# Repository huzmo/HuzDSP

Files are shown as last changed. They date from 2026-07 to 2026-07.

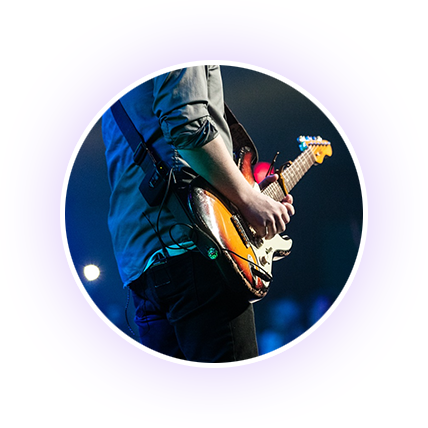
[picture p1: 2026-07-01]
Firmware/Drivers/lvgl-release-v9.5/demos/music/assets/png/480_png/cover_1.png

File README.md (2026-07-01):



<div align="center">
  <a href="https://github.com/github_username/repo_name">
    
  </a>

  <h3 align="center">HUZDSP</h3>

  <p align="center">
    Digital multi-effects guitar pedal featuring 2 input channels, 48kHz sampling, and 24-bit audio and open-source software with over 720 unique effect combinations per channel.
    <br />
    <br />
    &middot;
    <a href="https://youtube.com/shorts/TF-euVBcPBo?si=U8Q8GrKw2UyFqoOQ">View Demo</a>
    &middot;
  </p>
</div>

<!-- MARKDOWN LINKS & IMAGES -->
[product-screenshot]: images/screenshot.png

---

## Table of Contents

- [Overview](#overview)
- [Hardware](#hardware)
  - [Audio Signal Chain](#audio-signal-chain)
  - [Inputs / Outputs](#inputs--outputs)
  - [Power](#power)
  - [PCB / Physical Design](#pcb--physical-design)
- [Firmware](#firmware)
  - [Audio Processing Pipeline](#audio-processing-pipeline)
  - [Effect Framework](#effect-framework)
  - [Memory Map](#memory-map)
  - [Drivers / Peripherals](#drivers--peripherals)
- [Performance](#performance)
  - [CPU Utilization](#cpu-utilization)
  - [Memory Usage](#memory-usage)
  - [Audio Quality](#audio-quality)
- [Challenges](#challenges)
  - [Real-Time DSP Constraints](#real-time-dsp-constraints)
  - [Noise / Signal Integrity](#noise--signal-integrity)
  - [Resource Limitations](#resource-limitations)
  - [Modular Effect Integration](#modular-effect-integration)
- [Future Improvements](#future-improvements)
- [Media](#media)

---

## Overview

HuzDSP is a digital multi-effects guitar pedal, which pairs an STM32H743 microcontroller, a CS4270 audio codec, and an ILI9488 TFT display, running on FreeRTOS with an LVGL-based UI for real-time parameter control and effect chaining.

The goal of this project was to build a complete, professional-grade embedded audio platform rather than a single fixed-function pedal, with a 24-bit/48kHz signal path and a modular effects architecture that supports chaining multiple effects together, configuring them through UI, and extending the effect library without touching the core audio engine. Effects implemented so far include [effects list.

<p align="right">(<a href="#readme-top">back to top</a>)</p>

---

## Hardware

### Audio Signal Chain

Fundamentally, the signal flows through a linear path: beginning as an analog input from an external source, the signal passes through a buffer stage and is filtered with a cutoff at 27.6KHz to eliminate frequencies above the audible band. The filtered signal is then digitized by the ADC stage of the codec, after which the MCU reads and processes the data in real time before it is finally output and filtered back to analog on the way out.



### Inputs / Outputs

- 2x mono instrument inputs
- 2x mono instrument outputs
- 1x navigation encoder
- 3x parameter encoders
- 1x master volume potentiometer
- 480x320 LCD
- USB-C connector, reserved for future audio input/output to enable full audio interface functionality
- DC barrel jack for 9V-12V supply

### Power

The board is powered through a DC barrel jack and accepts 9V–12V, center-negative. Full supply voltage is used for the analog input/output op-amp stages. A reference voltage at half-supply is generated by a buffered resistor divider for biasing the op-amp stages. This rail is then stepped down to +5V for the codec and +3.3V for the remaining circuitry using DC-DC switching regulators, placed on the opposite end of the board from sensitive analog componentry to minimize switching noise coupling.

### PCB / Physical Design

A 4-layer board was chosen for this design, as it allows for larger ground planes with shorter return paths. A dedicated power layer simplifies routing and improves overall performance.

Physically, the board is designed to act as a shield for the LCD display; the mechanical design is simplified by having the board slot into the display and have the mounting holes lined up. This reduces the amount of wires present in the design and minimizes the length of the path the SPI and GPIO signals have to travel to reach the display processor.

To aid signal integrity, analog, power, and digital circuitry are separated from one another, and high-speed digital traces are routed away from analog sections. A solid ground plane sits directly below the first signal layer to reduce coupling between layers.

<p align="right">(<a href="#readme-top">back to top</a>)</p>

---

## Firmware

### Audio Processing Pipeline



### Effect Framework

One of the core design features of this project was to incorporate a framework for modular effects; effectively being able to add as many different kinds of effects as long as a simple template is followed. By decoupling parameter and state data from the effect's process function, an arbitrary process function can be passed into the effect loop without needing to manage unique local variables, previous states, or per-effect initialization logic elsewhere in the codebase.

Each effect is split into two parts: a structure that stores an assignable process function pointer, an array of parameters, and a block of state. The process function can be assigned freely at runtime and represents the per-sample algorithm used to achieve the desired effect. A pointer to the effect structure is passed into the process function, which reads the appropriate parameters and writes to the state block to hold constants, previous sample values, or any other data needed on the next sample cycle.

This framework not only allows for an intuitive, modular approach to adding new effects, but also saves memory by allocating each effect slot at compile-time and assigning the process function pointer at runtime, rather than dynamically creating and destroying effect instances during operation. This also guarantees exactly one instance of each effect exists in memory; if multiple effect slots use the same effect type, their function pointers all reference that single shared instance, regardless of how many slots use it.

### Memory Map

Memory is partitioned into two logical regions. Uncached allocations begin at `0x30000000` and are reserved for the audio path, while cacheable memory starting at `0x24000000` is used for display buffers. For the large display buffers, cacheability is a major advantage, as it allows for low-latency renders for frames which have not been flagged for change by LVGL. As audio data is a constant stream of changing values, caching would result in corrupt data, and continuously caching and uncaching would increase latency rather than reduce it. Therefore, audio buffers are allocated in a region which is strictly uncacheable. Each area can be read freely, which keeps managing state between the audio and display stacks simple.

### Drivers / Peripherals

- **LCD**: ILI9488 driver, adapted and optimized from an existing open-source base for this project's needs
- **Codec**: Custom CS4270 driver, written from scratch (I2C register configuration, reset sequencing)
- **SAI**: Used to read and write audio data to/from the codec
- **I2C**: Used to configure codec registers
- **SPI**: Used to drive the ILI9488 LCD display
- **Master volume potentiometer**: Interfaced by polling and filling a DMA buffer with data inside a dedicated task
- **Encoders**: Interfaced using hardware timers in encoder mode; push buttons are handled via interrupts

<p align="right">(<a href="#readme-top">back to top</a>)</p>

---

## Performance

### CPU Utilization



### Memory Usage



### Audio Quality



0.12ms measured latency with slight distortion caused by the aforementioned sources.

<p align="right">(<a href="#readme-top">back to top</a>)</p>

---

## Challenges

### Real-Time DSP Constraints

Running multiple DSP effects in a chain on a single sample-by-sample loop means every effect has a fixed time budget before the next audio sample is due. Effects like the flanger and chorus, which rely on buffered history and interpolation, had to be profiled and optimized carefully to stay within that budget without introducing audible glitches or dropouts.

### Noise / Signal Integrity

Keeping the analog signal path clean while running high-speed digital logic and switching power regulators on the same board meant analog, digital, and power circuitry had to be kept separate from one another, with high-speed digital routed away from analog sections. Coil whine from the TPS563200 buck converter was identified as one source of analog noise on the current board revision, and has been noted as a target for layout improvements in a future hardware revision.

### Resource Limitations

Balancing the audio buffers, display framebuffers, and RTOS task stacks within the STM32H743's memory map required explicit partitioning between cacheable and non-cacheable regions, along with careful DMA buffer placement, to avoid cache-coherency issues between the CPU and the DMA-driven audio and display peripherals.

### Modular Effect Integration

Designing the effect framework so new effects could be added without modifying the core audio engine took a few iterations to get right. The function-pointer-based dispatch approach, paired with per-effect parameter and state arrays, ended up being the design that struck the right balance between flexibility and the deterministic, low-overhead execution real-time audio processing demands.

<p align="right">(<a href="#readme-top">back to top</a>)</p>

---

## Future Improvements

- Address coil whine from the TPS563200 buck converter in a rev2 PCB layout
- Bring up USB-C audio interface functionality for full audio interface mode
- Expand the effect library beyond the current selection
- Continued UI refinement
- Implement EQ
  
<p align="right">(<a href="#readme-top">back to top</a>)</p>

---

## Media



Test Rig

<p align="right">(<a href="#readme-top">back to top</a>)</p>

---

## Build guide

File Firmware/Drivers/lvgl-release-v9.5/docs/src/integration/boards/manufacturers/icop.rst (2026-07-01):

====
ICOP
====

ICOP makes industrial computer hardware and the development tools for them.
ICOP offers an uncommon combination of hardware and software which distinguishes
them from other board vendors.

For a start, their products are not evaluation boards. They are ready-to-use
industrial PCs. They are a complete solution electrically and mechanically.

They are programmed with the Arduino IDE. You write your embedded application
logic and UI using the Arduino framework and its library ecosystem. Arduino is a
great abstraction to solve real problems when it's available for a platform.
ICOP is one such platform. You have access to all the popular open source
Arduino libraries. There is also support for installing Windows 11 on it.

Inside most of ICOP's panel PCs is an x86 processor. They are DM&P Vortex86
series chips. They execute 32-bit i586 machine code. This has interesting
implications, especially since the programming environment is as low-level as Arduino.
It's a rare case of an x86 CPU being used in a real-time setting.

Panel PCs
*********

These are PCs which are designed to be mounted in a panel. They are more
powerful than typical HMIs.

QEC-PPC-M-090T
--------------

This is an x86 panel PC which you can program using the Arduino IDE.
It has two cores. One core is dedicated to EtherCAT so the other is free
for application logic.

See the
`LVGL port repo <https://github.com/lvgl/lv_port_icop_qec_ppc_m_090t>`_
to get started creating a project for it with LVGL.

See the
`store page <https://www.icop.com.tw/product/QEC-PPC-M-090T>`_
for documentation and the ordering information.

Specs
~~~~~

CPU and Memory

- CPU: 533 MHz Vortex86EX2 32-bit x86 CPU
- RAM: 512MB/1GB DDR3
- Flash: 2GB SLC eMMC, 32MB SPI Flash

Display and Touch

- Resolution: 1024x600
- Display Size: 9"
- Interface: VGA
- Color Depth: 16-bit
- Technology: TFT
- DPI: 132 px/inch
- Touch Pad: Resistive

Connectivity

- Ethernet
- USB x3
- Headphone

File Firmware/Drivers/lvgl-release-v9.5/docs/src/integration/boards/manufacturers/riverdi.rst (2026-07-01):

=======
Riverdi
=======

`Riverdi <https://riverdi.com/>`__ specializes in making high quality
displays and the boards that carry them. They offer solutions that
range from simple display panels to intelligent displays, and
everything in between.

- STM32 Embedded Displays
- Single Board Computer Displays
- EVE Intelligent Displays
- HDMI Displays
- Evaluation Boards
- RGB, LVDS, MIPI DSI LCD Displays

STM32 Embedded Displays
***********************

The STM32 Embedded Displays have an STM32 MCU onboard which makes
it possible to embed an entire application into the device. LVGL
is well-suited to these boards.

lv_port_riverdi_stm32u5
-----------------------

`lv_port_riverdi_stm32u5 <https://github.com/lvgl/lv_port_riverdi_stm32u5>`_
is a port repo of LVGL which supports all 5-inch Riverdi STM32
Embedded Displays.

- `RVT50HQSNWC00-B <https://riverdi.com/product/5-inch-lcd-display-capacitive-touch-panel-optical-bonding-uxtouch-stm32u5-rvt50hqsnwc00-b>`_
- `RVT50HQSNWC00 <https://riverdi.com/product/5-inch-lcd-display-capacitive-touch-panel-air-bonding-uxtouch-stm32u5-rvt50hqsnwc00>`_
- `RVT50HQSFWCA0 <https://riverdi.com/product/5-inch-lcd-display-capacitive-touch-panel-air-bonding-atouch-frame-stm32u5-rvt50hqsfwca0>`_
- `RVT50HQSNWCA0 <https://riverdi.com/product/5-inch-lcd-display-capacitive-touch-panel-air-bonding-atouch-stm32u5-rvt50hqsnwca0>`_
- `RVT50HQSFWN00 <https://riverdi.com/product/5-inch-lcd-display-stm32u5-frame-rvt50hqsfwn00>`_
- `RVT50HQSNWN00 <https://riverdi.com/product/5-inch-lcd-display-stm32u5-rvt50hqsnwn00>`_

It natively supports the embedded NeoChrom GPU thanks to LVGL's support
for :ref:`NeoChrom <neochrom>`. NemaVG --- an extension to NeoChrom's
base support --- is implemented by this MCU.

The MCU has an LCD driver peripheral which LVGL uses to update the
display. See the :ref:`LTDC <stm32_ltdc_driver>` driver docs
for more info and how to customize its use.

Single-Board Computer Displays
******************************

The Single-Board Computer Displays are ready to use with
:ref:`Toradex <toradex>` Dahlia and Mallow carrier boards. In fact,
those carrier boards are compatible with all 34-pin Riverdi
MIPI-DSI displays.

Other Products
**************

The **EVE Intelligent Displays** feature a Bridgetek EVE graphics
controller IC so that the display can be controlled using
high-level drawing commands over a lower-bandwidth interface than
RGB, MIPI, etc.

The **HDMI Displays** sport an HDMI interface for streamlined
integration with PCs or SBCs. These displays are still low-profile
so they can be embedded into custom fixtures with ease.

The **Evaluation Boards** are affordable carrier boards for getting
Riverdi display panels up and running before designing or buying a
carrier board for a production application.

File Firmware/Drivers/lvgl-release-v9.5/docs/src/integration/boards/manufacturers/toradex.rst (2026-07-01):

.. include:: /include/substitutions.txt
.. _toradex:

=======
Toradex
=======

About Toradex
*************

Toradex specializes in manufacturing high-quality embedded computing solutions
based on System on Module units (SoMs). These boards and modules are designed to
meet the needs of industrial and commercial applications, offering reliability,
longevity, and scalability. Leveraging industry-standard frameworks like Yocto
Project, Toradex enables customers to create tailored embedded systems with
ease, ensuring compatibility and flexibility.

Products Portfolio
******************

Toradex offers a wide range of system-on-modules (SoMs) and carrier boards
designed for various applications and industries. Here's a basic overview to
help you navigate the portfolio.

Aquila
------

Aquila is a new System on Module standard expanding the Toradex portfolio to
new heights, offering unparalleled performance for computationally intensive
CPU, machine learning, and vision workloads.

To power next-gen's AI requirements in industrial and other harsh environments,
Aquila introduces a proven connector: the 400-pin board-to-board connector,
making the board extra reliable, especially in these environments.

Aquila Computer on Module:

    - `Aquila iMX95 <https://www.toradex.com/computer-on-modules/
      aquila-arm-family/nxp-imx95>`_
    - `Aquila AM69 <https://www.toradex.com/computer-on-modules/
      aquila-arm-family/ti-am69>`_

Aquila Carrier Boards:

    - `Clover <https://www.toradex.com/products/carrier-board/clover>`_
    - `Aquila Development Board <https://www.toradex.com/products/carrier-board/
      aquila-development-board-kit>`_

Apalis
------

Apalis is a scalable System on Module (SoM) / Computer on Module (CoM) family
that aims to provide high performance in a compact form factor. Apalis enables
the development of advanced and robust products within a short time and with
low risks. Apalis modules scale to the highest performance in the Toradex
product range, and they provide the most interfaces of any product line on the
314-pin MXM connectors. Apalis modules are suited to a larger number of
applications in such fields as healthcare, industrial automation, robotics,
smart cities and many more. Apalis modules are supported by Toradex software
offerings and the company's rich ecosystem of other products and services.

Apalis Computer on Module:

    - `Apalis iMX8 <https://www.toradex.com/computer-on-modules/
      apalis-arm-family/nxp-imx-8>`_
    - `Apalis iMX6 <https://www.toradex.com/computer-on-modules/
      apalis-arm-family/nxp-freescale-imx-6>`_
    - `Apalis T30 <https://www.toradex.com/computer-on-modules/
      apalis-arm-family/nvidia-tegra-3>`_

Apalis Carrier Boards:

    - `Ixora <https://www.toradex.com/products/carrier-board/
      ixora-carrier-board>`_
    - `Apalis Evaluation Board <https://www.toradex.com/products/carrier-board/
      ixora-carrier-board>`_

Colibri
-------

The Colibri Arm\ |reg| family consists of SODIMM-sized System on Modules (SoM) /
Computer on Modules (CoM). The family offers miniaturized modules based on NXP\ |reg|
i.MX 8X, i.MX 6ULL, i.MX 7, i.MX 6, Vybrid and NVIDIA\ |reg| Tegra SoCs. All these
modules are pin-compatible, ensuring scalability of applications developed on
them. The Colibri family delivers cost-performance-optimized designs. An
extensive range of Colibri-compatible carrier boards and accessories, such as
cameras and displays, is also available for easy product development on the
Colibri Arm family of modules.

Colibri Computer on Module:

    - `Colibri iMX8X <https://www.toradex.com/computer-on-modules/
      colibri-arm-family/nxp-imx-8x>`_
    - `Colibri T30 <https://www.toradex.com/computer-on-modules/
      colibri-arm-family/nvidia-tegra-3>`_
    - `Colibri T20 <https://www.toradex.com/computer-on-modules/
      colibri-arm-family/nvidia-tegra-2>`_
    - `Colibri iMX6 <https://www.toradex.com/computer-on-modules/
      colibri-arm-family/nxp-freescale-imx6>`_
    - `Colibri iMX7 <https://www.toradex.com/computer-on-modules/
      colibri-arm-family/nxp-freescale-imx7>`_
    - `Colibri iMXiMX6ULL8X <https://www.toradex.com/computer-on-modules/
      colibri-arm-family/nxp-imx6ull>`_
    - `Colibri VF61 <https://www.toradex.com/computer-on-modules/
      colibri-arm-family/nxp-freescale-vybrid-vf6xx>`_
    - `Colibri VF50 <https://www.toradex.com/computer-on-modules/
      colibri-arm-family/nxp-freescale-vybrid-vf5xx>`_

Colibri Carrier Boards:

    - `Colibri Evaluation Board <https://www.toradex.com/products/carrier-board/
      colibri-evaluation-board>`_
    - `Iris Carrier Board <https://www.toradex.com/products/carrier-board/
      iris-carrier-board>`_
    - `Viola Carrier Board <https://www.toradex.com/products/carrier-board/
      viola-carrier-board>`_
    - `Aster Carrier Board <https://www.toradex.com/products/carrier-board/
      aster-carrier-board>`_

Verdin
------

Verdin is a System on Module standard expanding on the successful Colibri and
Apalis form factors. It provides a revised, modern and capable interface set
and focuses on ease-of-use, robustness and being future-proof.

Verdin is similar sized to the Colibri but with a higher pin count. A DDR4
SODIMM edge connector provides a cost-effective, highly reliable, shock- and
vibration-resistant connection.

Verdin Computer on Module:

    - `Verdin iMX8M Plus <https://www.toradex.com/computer-on-modules/
      verdin-arm-family/nxp-imx-8m-plus>`_
    - `Verdin iMX8M Mini <https://www.toradex.com/computer-on-modules/
      verdin-arm-family/nxp-imx-8m-mini-nano>`_
    - `Verdin AM62 <https://www.toradex.com/computer-on-modules/
      verdin-arm-family/ti-am62>`_
    - `i.MX 95 Verdin Evaluation Kit <https://www.toradex.com/
      computer-on-modules/verdin-arm-family/nxp-imx95-evaluation-kit>`_
    - `Verdin iMX95 <https://www.toradex.com/computer-on-modules/
      verdin-arm-family/nxp-imx95-evaluation-kit#verdin-imx95>`_

Verdin Carrier Boards:

    - `Verdin Development Board with HDMI Adapter <https://www.toradex.com/
      products/carrier-board/verdin-development-board-kit>`_
    - `Dahlia Carrier Board with HDMI Adapter <https://www.toradex.com/products/
      carrier-board/dahlia-carrier-board-kit>`_
    - `Yavia <https://www.toradex.com/products/carrier-board/yavia>`_
    - `Mallow Carrier Board <https://www.toradex.com/products/carrier-board/
      mallow-carrier-board>`_
    - `Ivy Carrier Board <https://www.toradex.com/products/carrier-board/
      ivy-carrier-board>`_

TorizonOS
*********

TorizonOS is a Linux-based operating system developed by Toradex, tailored for
embedded systems. It is designed to simplify the development, deployment, and
maintenance of applications, especially in industrial and IoT settings.
Combining ease of use with powerful features like containerization and
over-the-air (OTA) updates, TorizonOS helps developers accelerate
time-to-market while ensuring robust performance and security for embedded
applications.

A TorizonOS guide to develop an application using LVGL can be found in the
:ref:`torizon-os-section` section.

More information is provided in the `Torizon documentation <https://www.torizon.
io/torizon-os>`_.

Toradex Examples
****************

There are existing ready to use repositories available. Click `here <https://
github.com/lvgl?q=lv_port_toradex&type=all&language=&sort=>`_ to check them out.

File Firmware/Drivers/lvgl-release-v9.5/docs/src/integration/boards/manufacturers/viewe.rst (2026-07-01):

=====
Viewe
=====

`Viewe <https://viewedisplay.com/>`__ specializes in comprehensive display solutions
for more than 10 Years with remarkable capability of software and hardware R&D,
factory manufacturing and sales service. Viewe not only offers one-stop
`bare display and touch solutions <https://viewedisplay.com/display-solutions/>`_
but also `embedded smart displays <https://viewedisplay.com/smart-solutions/>`_
with standard productions and tailored customization to develop your concepts
to reality.

Products Portfolio:
*******************

- Embedded Smart Displays

    - `IOT_AIOT Smart Display <https://viewedisplay.com/iot_aiot-smart-display/>`_
    - `Uart Smart Display <https://viewedisplay.com/uart-smart-display/>`_
    - `HDMI Display_Raspberry Pi Display <https://viewedisplay.com/hdmi-display-raspberry-pi-display/>`_
    - Arduino Display

TFT | OLED Display

    - `Sunlight Readable Display <https://viewedisplay.com/sunlight-readable-display/>`_
    - `AMOLED Displays <https://viewedisplay.com/amoled-display-list/>`_
    - `Transflective TFT Displays <https://viewedisplay.com/transflective-tft-display/>`_
    - `Standard TFT Displays <https://viewedisplay.com/standard-display/>`_
    - `Bar Display/Stretched TFT Display <https://viewedisplay.com/bar-display-stretched-display/>`_
    - `Square TFT Display <https://viewedisplay.com/square-display/>`_
    - `Round TFT Display <https://viewedisplay.com/round-display/>`_

IOT AIOT Smart Displays
***********************

The Viewe IOT AIOT Smart Displays are a series of displays that use ESP32
microcontrollers with integrated multi-modal interactions of GUI/voice/camera, ML/AI
edge computing, and seamless connectivity. UART/RS232/RS485/CAN Interfaces and
redundant IO interfaces are included to facilitate extended usage. LVGL/Arduino/ESP-IDF
is well-suited to these boards.

lv_port_viewe_7_espidf
----------------------

`lv_port_viewe_7_espidf <https://github.com/lvgl/lv_port_viewe_7_espidf>`_
is a port repository of LVGL which supports Viewe ESP32 S3 Smart Display 7.0 inch.
It is based on ESP-IDF and uses the ESP32-S3 microcontroller.

- `Viewe ESP32 S3 Smart Display <https://viewedisplay.com/product/esp32-7-inch-800x480-rgb-ips-tft-display-touch-screen-arduino-lvgl-uart/>`_

lv_port_viewe_knob_15_espidf
----------------------------

`lv_port_viewe_knob_15_espidf <https://github.com/lvgl/lv_port_viewe_knob_15_espidf>`_
is a port repository of LVGL which supports Viewe AMOLED Touch Knob Display.
It is based on ESP-IDF and uses the ESP32-S3 microcontroller.

- `Viewe AMOLED Touch Knob Display <https://viewedisplay.com/product/esp32-1-5-inch-466x466-round-amoled-knob-display-touch-screen-arduino-lvgl/>`_

UART Smart Displays
*******************

The Viewe UART Smart Displays are a series of displays that use ESP32 and STM32
microcontrollers with UART/RS232/RS485/CAN Interface and have IO interface for
connecting to peripherals. LVGL is well-suited to these boards.

lv_port_viewe_7_espidf
----------------------

`lv_port_viewe_7_espidf <https://github.com/lvgl/lv_port_viewe_7_espidf>`_
is a port repository of LVGL which supports Viewe ESP32 S3 Smart Display 7.0 inch.
It is based on ESP-IDF and uses the ESP32-S3 microcontroller.

- `Viewe ESP32 S3 Smart Display <https://viewedisplay.com/product/esp32-7-inch-800x480-rgb-ips-tft-display-touch-screen-arduino-lvgl-uart/>`_

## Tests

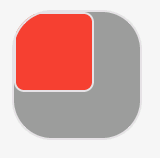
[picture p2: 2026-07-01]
Firmware/Drivers/lvgl-release-v9.5/docs/src/_static/images/clip_corner_2_result.png

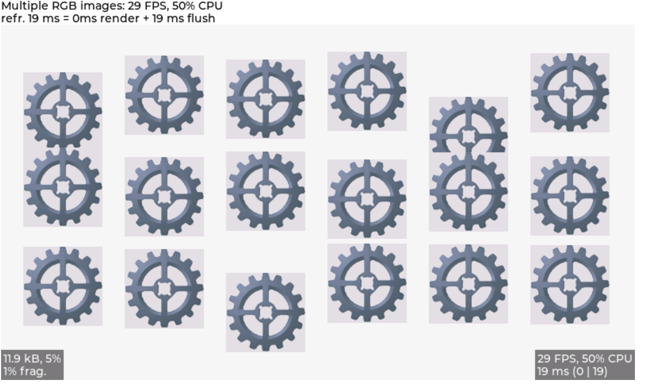
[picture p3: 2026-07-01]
Firmware/Drivers/lvgl-release-v9.5/demos/benchmark/screenshot1.png

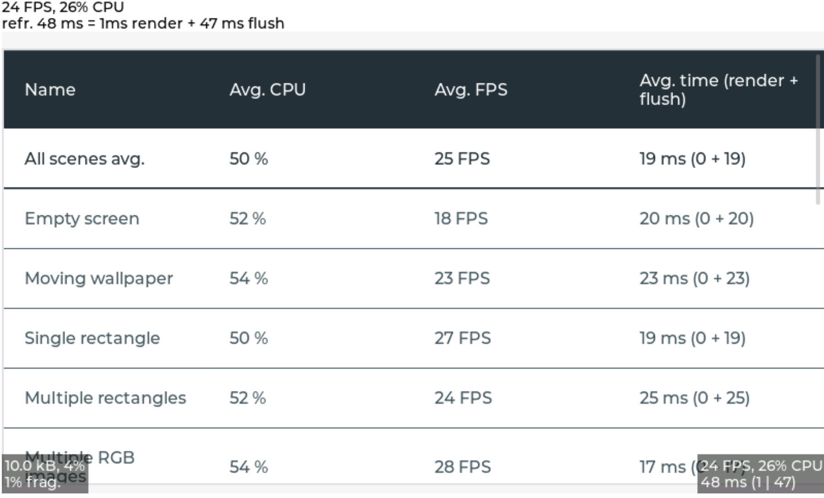
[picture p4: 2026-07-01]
Firmware/Drivers/lvgl-release-v9.5/demos/benchmark/screenshot2.png

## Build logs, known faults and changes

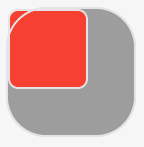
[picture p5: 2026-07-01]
Firmware/Drivers/lvgl-release-v9.5/docs/src/_static/images/clip_corner_1_problem_being_solved.png

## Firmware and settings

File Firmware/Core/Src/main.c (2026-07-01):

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
/* Includes ------------------------------------------------------------------*/
#include "main.h"
#include "FreeRTOS.h"
#include "cmsis_os2.h"

/* USER CODE BEGIN Includes */
#include "ili9488.h"
#include "lvgl.h"
#include "ui.h"
#include "ui_events.h"
#include "tuner.h"
#include "screen.h"
#include "cs4270.h"
#include "AudioPath.h"
#include "task.h"
/* USER CODE END Includes */

/* USER CODE BEGIN PD */
#define DISPLAY_WIDTH  480
#define DISPLAY_HEIGHT 320
#define BUFF_SIZE (DISPLAY_WIDTH * 10)
#define LVGL_BUF_PIXELS  (DISPLAY_WIDTH * 10)
#define RGB666_BUF_BYTES (LVGL_BUF_PIXELS * 3)

#define AUDIO_BUFFER_SIZE 256
/* USER CODE END PD */

ADC_HandleTypeDef hadc3;

I2C_HandleTypeDef hi2c2;

SAI_HandleTypeDef hsai_BlockA2;
SAI_HandleTypeDef hsai_BlockB2;
DMA_HandleTypeDef hdma_sai2_b;
DMA_HandleTypeDef hdma_sai2_a;

SPI_HandleTypeDef hspi1;
DMA_HandleTypeDef hdma_spi1_tx;

TIM_HandleTypeDef htim2;
TIM_HandleTypeDef htim3;
TIM_HandleTypeDef htim4;
TIM_HandleTypeDef htim8;

/* Definitions for InputTask */
osThreadId_t InputTaskHandle;
const osThreadAttr_t InputTask_attributes = {
  .name = "InputTask",
  .stack_size = 512 * 4,
  .priority = (osPriority_t) osPriorityHigh,
};
/* Definitions for lvglTick */
osThreadId_t lvglTickHandle;
const osThreadAttr_t lvglTick_attributes = {
  .name = "lvglTick",
  .stack_size = 512 * 4,
  .priority = (osPriority_t) osPriorityHigh,
};
/* Definitions for lvglTimer */
osThreadId_t lvglTimerHandle;
const osThreadAttr_t lvglTimer_attributes = {
  .name = "lvglTimer",
  .stack_size = 4096 * 4,
  .priority = (osPriority_t) osPriorityHigh,
};
/* Definitions for audioTask */
osThreadId_t audioTaskHandle;
const osThreadAttr_t audioTask_attributes = {
  .name = "audioTask",
  .stack_size = 2048 * 4,
  .priority = (osPriority_t) osPriorityRealtime,
};
/* Definitions for lvgl_mutex */
osMutexId_t lvgl_mutexHandle;
const osMutexAttr_t lvgl_mutex_attributes = {
  .name = "lvgl_mutex"
};
/* Definitions for sem_flush */
osSemaphoreId_t sem_flushHandle;
const osSemaphoreAttr_t sem_flush_attributes = {
  .name = "sem_flush"
};
/* Definitions for sem_audio */
osSemaphoreId_t sem_audioHandle;
const osSemaphoreAttr_t sem_audio_attributes = {
  .name = "sem_audio"
};
/* USER CODE BEGIN PV */
// UI Variables
static lv_color_t buf_1[LVGL_BUF_PIXELS] __attribute__((section(".displaybuffer")));
static lv_color_t buf_2[LVGL_BUF_PIXELS] __attribute__((section(".displaybuffer")));
static uint8_t    rgb666_buf[RGB666_BUF_BYTES] __attribute__((section(".displaybuffer")));

extern lv_group_t *encoder_group;
volatile static int32_t last_encoder_value = 0;
lv_indev_t *encoder_indev = NULL;

// Audio Variables prob refactor
static int32_t adcBuf[AUDIO_BUFFER_SIZE] 		__attribute__ ((section(".audiobuffer")));
static int32_t dacBuf[AUDIO_BUFFER_SIZE] 		__attribute__ ((section(".audiobuffer")));

static volatile int32_t *inBufPtr 		__attribute__ ((section(".audiobuffer")));
static volatile int32_t *outBufPtr 		__attribute__ ((section(".audiobuffer")));

volatile uint8_t processHalfFlag		__attribute__ ((section(".audiobuffer")));

extern AudioChannel_t Channel1;
extern AudioChannel_t Channel2;

volatile float volume = 1.0f;
volatile uint8_t paramSide = 0;
/* USER CODE END PV */

void SystemClock_Config(void);
void PeriphCommonClock_Config(void);
static void MPU_Config(void);
static void MX_GPIO_Init(void);
static void MX_DMA_Init(void);
static void MX_SPI1_Init(void);
static void MX_TIM4_Init(void);
static void MX_SAI2_Init(void);
static void MX_I2C2_Init(void);
static void MX_ADC3_Init(void);
static void MX_TIM2_Init(void);
static void MX_TIM3_Init(void);
static void MX_TIM8_Init(void);
void StartInputTask(void *argument);
void LVGLTick(void *argument);
void LVGLTimer(void *argument);
void StartAudioTask(void *argument);

/* USER CODE BEGIN 0 */

static void my_flush_cb(lv_display_t *disp, const lv_area_t *area, uint8_t *px_map)
{
    uint32_t n_px = lv_area_get_size(area);
    uint16_t *src = (uint16_t *)px_map;
    uint8_t  *dst = rgb666_buf;

    for (uint32_t i = 0; i < n_px; i++)
    {
        uint16_t c = *src++;
        *dst++ = ((c >> 11) & 0x1F) << 3;
        *dst++ = ((c >>  5) & 0x3F) << 2;
        *dst++ = ((c >>  0) & 0x1F) << 3;
    }

    uint32_t  remaining = n_px * 3;
    uint8_t  *ptr       = rgb666_buf;

    setAddrWindow(area->x1, area->y1, area->x2, area->y2);
    DC_DATA();
    CS_A();

    // Blocking for all but final chunk
    while (remaining > 65535)
    {
        HAL_SPI_Transmit(&hspi1, ptr, 65535, HAL_MAX_DELAY);
        ptr       += 65535;
        remaining -= 65535;
    }

    // Final chunk async — callback releases semaphore

    HAL_SPI_Transmit_DMA(&hspi1, ptr, (uint16_t)remaining);
    osSemaphoreAcquire(sem_flushHandle, osWaitForever);

    lv_display_flush_ready(disp);
}

void HAL_SPI_TxCpltCallback(SPI_HandleTypeDef *hspi)
{
    if (hspi == &hspi1)
    {
        CS_D();
        osSemaphoreRelease(sem_flushHandle);
    }
}

static void encoder_read_cb(lv_indev_t *indev, lv_indev_data_t *data)
{
   // Button
   data->state = HAL_GPIO_ReadPin(NavEncoder_SW_GPIO_Port, NavEncoder_SW_Pin) == GPIO_PIN_RESET
                 ? LV_INDEV_STATE_PRESSED : LV_INDEV_STATE_RELEASED;
   // Rotation with wraparound
   int32_t current_val = (int32_t)__HAL_TIM_GET_COUNTER(&htim4);
   int32_t diff = current_val - last_encoder_value;
   if (diff > 32767)  diff -= 65536;
   if (diff < -32767) diff += 65536;
   last_encoder_value = current_val;
   data->enc_diff = (int16_t)diff;
}

void HAL_SAI_RxHalfCpltCallback(SAI_HandleTypeDef *hsai) {

	inBufPtr  = &(adcBuf[0]);
	outBufPtr = &(dacBuf[0]);

	osSemaphoreRelease(sem_audioHandle);

}

void HAL_SAI_RxCpltCallback(SAI_HandleTypeDef *hsai) {

	inBufPtr  = &(adcBuf[AUDIO_BUFFER_SIZE/2]);
	outBufPtr = &(dacBuf[AUDIO_BUFFER_SIZE/2]);

	osSemaphoreRelease(sem_audioHandle);

}

void HAL_GPIO_EXTI_Callback(uint16_t GPIO_Pin)
{
    if(GPIO_Pin == Encoder_3W_Pin)
    {
    	HAL_GPIO_TogglePin(LED_GPIO_Port, LED_Pin);
    	paramSide ^= 1;
    }
}

/* USER CODE END 0 */

/**
  * @brief  The application entry point.
  * @retval int
  */
int main(void)
{

  /* MPU Configuration--------------------------------------------------------*/
  MPU_Config();

  /* Enable the CPU Cache */

  /* Enable I-Cache---------------------------------------------------------*/
  SCB_EnableICache();

  /* Enable D-Cache---------------------------------------------------------*/
  SCB_EnableDCache();

  /* MCU Configuration--------------------------------------------------------*/

  /* Reset of all peripherals, Initializes the Flash interface and the Systick. */
  HAL_Init();

  /* Configure the system clock */
  SystemClock_Config();

  /* Configure the peripherals common clocks */
  PeriphCommonClock_Config();

  /* Initialize all configured peripherals */
  MX_GPIO_Init();
  MX_DMA_Init();
  MX_SPI1_Init();
  MX_TIM4_Init();
  MX_SAI2_Init();
  MX_I2C2_Init();
  MX_ADC3_Init();
  MX_TIM2_Init();
  MX_TIM3_Init();
  MX_TIM8_Init();
  /* USER CODE BEGIN 2 */
  ILI9488_Init();
  lv_init();

  lv_display_t *disp = lv_display_create(DISPLAY_WIDTH, DISPLAY_HEIGHT);
  lv_display_set_flush_cb(disp, my_flush_cb);
  lv_display_set_buffers(disp, buf_1, buf_2, sizeof(buf_1),
                         LV_DISPLAY_RENDER_MODE_PARTIAL);

  HAL_TIM_Encoder_Start(&htim4, TIM_CHANNEL_ALL);
  encoder_indev = lv_indev_create();
  lv_indev_set_type(encoder_indev, LV_INDEV_TYPE_ENCODER);
  lv_indev_set_read_cb(encoder_indev, encoder_read_cb);

  encoder_group = lv_group_create();
  lv_group_set_default(encoder_group);
  lv_indev_set_group(encoder_indev, encoder_group);

  ui_init();
  /* USER CODE END 2 */

  /* Init scheduler */
  osKernelInitialize();
  /* Create the mutex(es) */
  /* creation of lvgl_mutex */
  lvgl_mutexHandle = osMutexNew(&lvgl_mutex_attributes);

  /* USER CODE BEGIN RTOS_MUTEX */
  /* add mutexes, ... */
  /* USER CODE END RTOS_MUTEX */

  /* Create the semaphores(s) */
  /* creation of sem_flush */
  sem_flushHandle = osSemaphoreNew(1, 0, &sem_flush_attributes);

  /* creation of sem_audio */
  sem_audioHandle = osSemaphoreNew(1, 0, &sem_audio_attributes);

  /* USER CODE BEGIN RTOS_SEMAPHORES */
  /* add semaphores, ... */
  /* USER CODE END RTOS_SEMAPHORES */

  /* USER CODE BEGIN RTOS_TIMERS */
  /* start timers, add new ones, ... */
  /* USER CODE END RTOS_TIMERS */

  /* USER CODE BEGIN RTOS_QUEUES */
  /* add queues, ... */
  /* USER CODE END RTOS_QUEUES */

  /* Create the thread(s) */
  /* creation of InputTask */
  InputTaskHandle = osThreadNew(StartInputTask, NULL, &InputTask_attributes);

  /* creation of lvglTick */
  lvglTickHandle = osThreadNew(LVGLTick, NULL, &lvglTick_attributes);

  /* creation of lvglTimer */
  lvglTimerHandle = osThreadNew(LVGLTimer, NULL, &lvglTimer_attributes);

  /* creation of audioTask */
  audioTaskHandle = osThreadNew(StartAudioTask, NULL, &audioTask_attributes);

  /* USER CODE BEGIN RTOS_THREADS */
  /* add threads, ... */
  /* USER CODE END RTOS_THREADS */

  /* USER CODE BEGIN RTOS_EVENTS */
  /* add events, ... */
  /* USER CODE END RTOS_EVENTS */

  /* Start scheduler */
  osKernelStart();

  /* We should never get here as control is now taken by the scheduler */

  /* Infinite loop */
  /* USER CODE BEGIN WHILE */
  while (1)
  {

    /* USER CODE END WHILE */

    /* USER CODE BEGIN 3 */
  }
  /* USER CODE END 3 */
}

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
/* USER CODE BEGIN Header_StartInputTask */
/**
  * @brief  Function implementing the InputTask thread.
  * @param  argument: Not used
  * @retval None
  */
/* USER CODE END Header_StartInputTask */
void StartInputTask(void *argument)
{
  /* USER CODE BEGIN 5 */
	HAL_GPIO_TogglePin(LED_GPIO_Port, LED_Pin);
	HAL_TIM_Encoder_Start(&htim2, TIM_CHANNEL_ALL);
	HAL_TIM_Encoder_Start(&htim3, TIM_CHANNEL_ALL);
	HAL_TIM_Encoder_Start(&htim8, TIM_CHANNEL_ALL);

	static uint32_t lastEnc1 = 0, lastEnc2 = 0, lastEnc3 = 0;
  /* Infinite loop */
  for(;;)
  {
      osDelay(pdMS_TO_TICKS(200));

      // Volume Pot
      uint32_t raw = 0;
      HAL_ADC_Start(&hadc3);
      if (HAL_ADC_PollForConversion(&hadc3, 10) == HAL_OK) {
          raw = HAL_ADC_GetValue(&hadc3);
      }
      HAL_ADC_Stop(&hadc3);
      int32_t volume_percent = (((65535 - raw) * 100) >> 16) + 1;
      volume = (65535 - raw) / 65535.0f; // for 0-1 audio scaling

      // Parameter Encoders
      uint32_t enc1 = __HAL_TIM_GET_COUNTER(&htim8);
      uint32_t enc2 = __HAL_TIM_GET_COUNTER(&htim3);
      uint32_t enc3 = __HAL_TIM_GET_COUNTER(&htim2);

      int32_t delta1 = (int16_t)(enc1 - lastEnc1);
      int32_t delta2 = (int16_t)(enc2 - lastEnc2);
      int32_t delta3 = (int16_t)(enc3 - lastEnc3);

      lastEnc1 = enc1; lastEnc2 = enc2; lastEnc3 = enc3;

      if (g_display_mgr.activeSlotIdx > 2) offset = 3;
      AudioChannel_t* pChannel = (g_display_mgr.activeSlotIdx < 5) ? &Channel1 : &Channel2;
	  int internal_slot_idx = (g_display_mgr.activeSlotIdx < 5) ? g_display_mgr.activeSlotIdx : g_display_mgr.activeSlotIdx - 5;

	  // keep this small so other lvgl tasks dont get blocked for a long time
	  osMutexAcquire(lvgl_mutexHandle, osWaitForever);

	  lv_arc_set_value(ui_VolumeIndicator, volume_percent);

	  if (lv_scr_act() == ui_Pedal) {
		  if (paramSide == 0) {
			lv_arc_set_value(ui_Parameter,  lv_arc_get_value(ui_Parameter)  + delta1);
			lv_arc_set_value(ui_Parameter1, lv_arc_get_value(ui_Parameter1) + delta2);
			lv_arc_set_value(ui_Parameter2, lv_arc_get_value(ui_Parameter2) + delta3);

			lv_label_set_text_fmt(ui_ParamValue, "%ld", lv_arc_get_value(ui_Parameter));
			lv_label_set_text_fmt(ui_ParamValue1, "%ld", lv_arc_get_value(ui_Parameter1));
			lv_label_set_text_fmt(ui_ParamValue2, "%ld", lv_arc_get_value(ui_Parameter2));

			pChannel->chain[internal_slot_idx].params[0] = lv_arc_get_value(ui_Parameter);
			pChannel->chain[internal_slot_idx].params[1] = lv_arc_get_value(ui_Parameter1);
			pChannel->chain[internal_slot_idx].params[2] = lv_arc_get_value(ui_Parameter2);

		} else {
			lv_arc_set_value(ui_Parameter3, lv_arc_get_value(ui_Parameter3) + delta1);
			lv_arc_set_value(ui_Parameter4, lv_arc_get_value(ui_Parameter4) + delta2);
			lv_arc_set_value(ui_Parameter5, lv_arc_get_value(ui_Parameter5) + delta3);

			lv_label_set_text_fmt(ui_ParamValue3, "%ld", lv_arc_get_value(ui_Parameter3));
			lv_label_set_text_fmt(ui_ParamValue4, "%ld", lv_arc_get_value(ui_Parameter4));
			lv_label_set_text_fmt(ui_ParamValue5, "%ld", lv_arc_get_value(ui_Parameter5));

			pChannel->chain[internal_slot_idx].params[3] = lv_arc_get_value(ui_Parameter3);
			pChannel->chain[internal_slot_idx].params[4] = lv_arc_get_value(ui_Parameter4);
			pChannel->chain[internal_slot_idx].params[5] = lv_arc_get_value(ui_Parameter5);
		}
	}

    //syncChannelFromDisplay(&Channel1);
    //syncChannelFromDisplay(&Channel2);

    osMutexRelease(lvgl_mutexHandle);
  }
  /* USER CODE END 5 */
}

/* USER CODE BEGIN Header_LVGLTick */
/**
* @brief Function implementing the lvglTick thread.
* @param argument: Not used
* @retval None
*/
/* USER CODE END Header_LVGLTick */
void LVGLTick(void *argument)
{
  /* USER CODE BEGIN LVGLTick */
  /* Infinite loop */
  for(;;)
  {
      lv_tick_inc(5);
      osDelay(5);
  }
  /* USER CODE END LVGLTick */
}

/* USER CODE BEGIN Header_LVGLTimer */
/**
* @brief Function implementing the lvglTimer thread.
* @param argument: Not used
* @retval None
*/
/* USER CODE END Header_LVGLTimer */
void LVGLTimer(void *argument)
{
  /* USER CODE BEGIN LVGLTimer */
  /* Infinite loop */
  for(;;)
  {
	  osMutexAcquire(lvgl_mutexHandle, osWaitForever);
	  lv_timer_handler();
	  osMutexRelease(lvgl_mutexHandle);
      osDelay(10);
  }
  /* USER CODE END LVGLTimer */
}

/* USER CODE BEGIN Header_StartAudioTask */
/**
* @brief Function implementing the audioTask thread.
* @param argument: Not used
* @retval None
*/
/* USER CODE END Header_StartAudioTask */
void StartAudioTask(void *argument)
{
  /* USER CODE BEGIN StartAudioTask */
	CS4270_Init();
	audioPathInit(&Channel1, &Channel2);
	HAL_SAI_Transmit_DMA(&hsai_BlockA2, (uint8_t *) dacBuf, AUDIO_BUFFER_SIZE);
	HAL_SAI_Receive_DMA(&hsai_BlockB2, (uint8_t *) adcBuf, AUDIO_BUFFER_SIZE);
  /* Infinite loop */
  for(;;)
  {
	  osSemaphoreAcquire(sem_audioHandle, osWaitForever);

  	static float leftIn		= 0.0f;
  	static float rightIn	= 0.0f;

  	static float leftOut	= 0.0f;
  	static float rightOut	= 0.0f;

  	for (uint16_t sampleIndex = 0; sampleIndex < (AUDIO_BUFFER_SIZE/2) - 1; sampleIndex += 2) {

  		syncChannelFromDisplay(&Channel1);
  		syncChannelFromDisplay(&Channel2);

  		// Extract 24-bits via bit mask
  		inBufPtr[sampleIndex]		&= 0xFFFFFF;
  		inBufPtr[sampleIndex + 1]	&= 0xFFFFFF;

  		if (inBufPtr[sampleIndex] & 0x800000) {
  			inBufPtr[sampleIndex] |= ~0xFFFFFF;
  		}

  		if (inBufPtr[sampleIndex + 1] & 0x800000) {
  			inBufPtr[sampleIndex + 1] |= ~0xFFFFFF;
  		}

  		// Normalise
  		leftIn  = (float) inBufPtr[sampleIndex]     / (float) (0x7FFFFF);
  		rightIn = (float) inBufPtr[sampleIndex + 1] / (float) (0x7FFFFF);

  		// flipped left and right because I made the wire shorter and it doesnt reach the port so its easier and less wasteful to just switch the assignments in software
  		leftOut  = effectsRouter(&Channel2, rightIn) * volume;
  		rightOut = effectsRouter(&Channel1, leftIn) * volume;

  		if (leftOut < -1.0f) {
  			leftOut = -1.0f;

  		} else if (leftOut > 1.0f) {
  			leftOut =  1.0f;
  		}

  		if (rightOut < -1.0f) {
  			rightOut = -1.0f;
  		} else if (rightOut > 1.0f) {
  			rightOut =  1.0f;
  		}

  		// Scale to 24-bit signed integer and set output buffer
  		outBufPtr[sampleIndex]	   = (int32_t) (leftOut  * 0x7FFFFF);
  		outBufPtr[sampleIndex + 1] = (int32_t) (rightOut * 0x7FFFFF);
  	}
  }
  /* USER CODE END StartAudioTask */
}

 /* MPU Configuration */

void MPU_Config(void)
{
  MPU_Region_InitTypeDef MPU_InitStruct = {0};

  /* Disables the MPU */
  HAL_MPU_Disable();

  /** Initializes and configures the Region and the memory to be protected
  */
  MPU_InitStruct.Enable = MPU_REGION_ENABLE;
  MPU_InitStruct.Number = MPU_REGION_NUMBER0;
  MPU_InitStruct.BaseAddress = 0x0;
  MPU_InitStruct.Size = MPU_REGION_SIZE_4GB;
  MPU_InitStruct.SubRegionDisable = 0x87;
  MPU_InitStruct.TypeExtField = MPU_TEX_LEVEL0;
  MPU_InitStruct.AccessPermission = MPU_REGION_NO_ACCESS;
  MPU_InitStruct.DisableExec = MPU_INSTRUCTION_ACCESS_DISABLE;
  MPU_InitStruct.IsShareable = MPU_ACCESS_SHAREABLE;
  MPU_InitStruct.IsCacheable = MPU_ACCESS_NOT_CACHEABLE;
  MPU_InitStruct.IsBufferable = MPU_ACCESS_NOT_BUFFERABLE;

  HAL_MPU_ConfigRegion(&MPU_InitStruct);

  /** Initializes and configures the Region and the memory to be protected
  */
  MPU_InitStruct.Number = MPU_REGION_NUMBER1;
  MPU_InitStruct.BaseAddress = 0x24000000;
  MPU_InitStruct.Size = MPU_REGION_SIZE_512KB;
  MPU_InitStruct.SubRegionDisable = 0x0;
  MPU_InitStruct.TypeExtField = MPU_TEX_LEVEL1;
  MPU_InitStruct.AccessPermission = MPU_REGION_FULL_ACCESS;
  MPU_InitStruct.DisableExec = MPU_INSTRUCTION_ACCESS_ENABLE;
  MPU_InitStruct.IsShareable = MPU_ACCESS_NOT_SHAREABLE;
  MPU_InitStruct.IsCacheable = MPU_ACCESS_CACHEABLE;
  MPU_InitStruct.IsBufferable = MPU_ACCESS_BUFFERABLE;

  HAL_MPU_ConfigRegion(&MPU_InitStruct);

  /** Initializes and configures the Region and the memory to be protected
  */
  MPU_InitStruct.Number = MPU_REGION_NUMBER2;
  MPU_InitStruct.TypeExtField = MPU_TEX_LEVEL0;

  HAL_MPU_ConfigRegion(&MPU_InitStruct);

  /** Initializes and configures the Region and the memory to be protected
  */
  MPU_InitStruct.Number = MPU_REGION_NUMBER3;
  MPU_InitStruct.BaseAddress = 0x30000000;
  MPU_InitStruct.Size = MPU_REGION_SIZE_256KB;
  MPU_InitStruct.IsShareable = MPU_ACCESS_SHAREABLE;
  MPU_InitStruct.IsCacheable = MPU_ACCESS_NOT_CACHEABLE;
  MPU_InitStruct.IsBufferable = MPU_ACCESS_NOT_BUFFERABLE;

  HAL_MPU_ConfigRegion(&MPU_InitStruct);

  /** Initializes and configures the Region and the memory to be protected
  */
  MPU_InitStruct.Number = MPU_REGION_NUMBER4;
  MPU_InitStruct.BaseAddress = 0x38000000;
  MPU_InitStruct.Size = MPU_REGION_SIZE_64KB;

  HAL_MPU_ConfigRegion(&MPU_InitStruct);
  /* Enables the MPU */
  HAL_MPU_Enable(MPU_PRIVILEGED_DEFAULT);

}

/**
  * @brief  Period elapsed callback in non blocking mode
  * @note   This function is called  when TIM1 interrupt took place, inside
  * HAL_TIM_IRQHandler(). It makes a direct call to HAL_IncTick() to increment
  * a global variable "uwTick" used as application time base.
  * @param  htim : TIM handle
  * @retval None
  */
void HAL_TIM_PeriodElapsedCallback(TIM_HandleTypeDef *htim)
{
  if (htim->Instance == TIM1)
  {
    HAL_IncTick();
  }
}

/**
  * @brief  This function is executed in case of error occurrence.
  * @retval None
  */
void Error_Handler(void)
{
  /* USER CODE BEGIN Error_Handler_Debug */
  /* User can add his own implementation to report the HAL error return state */
  __disable_irq();
  while (1)
  {
  }
  /* USER CODE END Error_Handler_Debug */
}
#ifdef USE_FULL_ASSERT
/**
  * @brief  Reports the name of the source file and the source line number
  *         where the assert_param error has occurred.
  * @param  file: pointer to the source file name
  * @param  line: assert_param error line source number
  * @retval None
  */
void assert_failed(uint8_t *file, uint32_t line)
{
  /* USER CODE BEGIN 6 */
  /* User can add his own implementation to report the file name and line number,
     ex: printf("Wrong parameters value: file %s on line %d\r\n", file, line) */
  /* USER CODE END 6 */
}
#endif /* USE_FULL_ASSERT */

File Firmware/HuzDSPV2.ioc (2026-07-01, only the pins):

Mcu.UserName=STM32H743VITx
PA0.GPIO_Label=Encoder_1A
PA0.Signal=S_TIM2_CH1_ETR
PA1.GPIO_Label=Encoder_1B
PA1.Signal=S_TIM2_CH2
PA6.GPIO_Label=Encoder_2B
PA6.Signal=S_TIM3_CH1
PA7.GPIO_Label=Encoder_2A
PA7.Signal=S_TIM3_CH2
PB10.Signal=I2C2_SCL
PB11.Signal=I2C2_SDA
PB5.GPIO_Label=NavEncoder_SW
PB5.Signal=GPIO_Input
PB6.Signal=S_TIM4_CH1
PB7.Signal=S_TIM4_CH2
PC13.GPIO_Label=LED
PC13.Signal=GPIO_Output
PC3_C.GPIO_Label=Volume
PC3_C.Signal=ADC3_INP1
PC5.GPIO_Label=Encoder_3W
PC5.Signal=GPXTI5
PC6.GPIO_Label=Encoder_3B
PC6.Signal=S_TIM8_CH1
PC7.GPIO_Label=Encoder_3A
PC7.Signal=S_TIM8_CH2
PD11.Signal=SAI2_SD_A
PD2.GPIO_Label=TFT_CS
PD2.Signal=GPIO_Output
PD3.GPIO_Label=TFT_RST
PD3.Signal=GPIO_Output
PD5.GPIO_Label=TFT_DC
PD5.Signal=GPIO_Output
PD6.GPIO_Label=TFT_BL
PD6.Signal=GPIO_Output
PD7.Signal=SPI1_MOSI
PE11.Signal=SAI2_SD_B
PE12.Signal=SAI2_SCK_B
PE13.Signal=SAI2_FS_B
PE14.Signal=SAI2_MCLK_B
PE15.GPIO_Label=Codec_RST
PE15.Signal=GPIO_Output

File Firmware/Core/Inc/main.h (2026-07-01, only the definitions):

#define LED_Pin GPIO_PIN_13
#define LED_GPIO_Port GPIOC
#define Volume_Pin GPIO_PIN_3
#define Volume_GPIO_Port GPIOC
#define Encoder_1A_Pin GPIO_PIN_0
#define Encoder_1A_GPIO_Port GPIOA
#define Encoder_1B_Pin GPIO_PIN_1
#define Encoder_1B_GPIO_Port GPIOA
#define Encoder_2B_Pin GPIO_PIN_6
#define Encoder_2B_GPIO_Port GPIOA
#define Encoder_2A_Pin GPIO_PIN_7
#define Encoder_2A_GPIO_Port GPIOA
#define Encoder_3W_Pin GPIO_PIN_5
#define Encoder_3W_GPIO_Port GPIOC
#define Encoder_3W_EXTI_IRQn EXTI9_5_IRQn
#define Codec_RST_Pin GPIO_PIN_15
#define Codec_RST_GPIO_Port GPIOE
#define Encoder_3B_Pin GPIO_PIN_6
#define Encoder_3B_GPIO_Port GPIOC
#define Encoder_3A_Pin GPIO_PIN_7
#define Encoder_3A_GPIO_Port GPIOC
#define TFT_CS_Pin GPIO_PIN_2
#define TFT_CS_GPIO_Port GPIOD
#define TFT_RST_Pin GPIO_PIN_3
#define TFT_RST_GPIO_Port GPIOD
#define TFT_DC_Pin GPIO_PIN_5
#define TFT_DC_GPIO_Port GPIOD
#define TFT_BL_Pin GPIO_PIN_6
#define TFT_BL_GPIO_Port GPIOD
#define NavEncoder_SW_Pin GPIO_PIN_5
#define NavEncoder_SW_GPIO_Port GPIOB

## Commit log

2025-12-15 Initial commit – HuzDSP firmware
2025-12-15 Added Interrupts and Queues
2026-06-29 Added PDB Gerbers
    [top_level_Copper_Signal_1.gbr, top_level_Copper_Signal_2.gbr, top_level_Copper_Signal_Bot.gbr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]
2026-07-01 Commit firmware
    [code-format.cfg]

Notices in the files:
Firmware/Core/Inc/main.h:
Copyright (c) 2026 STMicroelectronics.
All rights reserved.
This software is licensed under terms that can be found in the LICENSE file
